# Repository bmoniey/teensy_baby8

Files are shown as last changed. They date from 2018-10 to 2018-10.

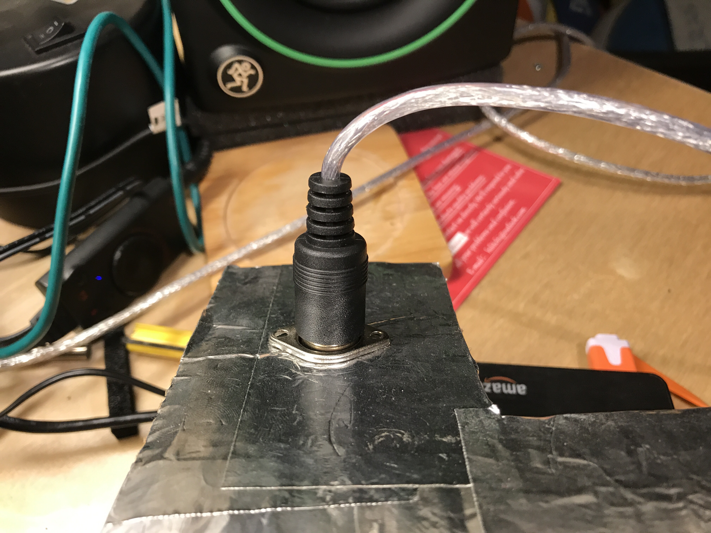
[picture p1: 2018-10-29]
doc/pics/IMG_2280.JPG

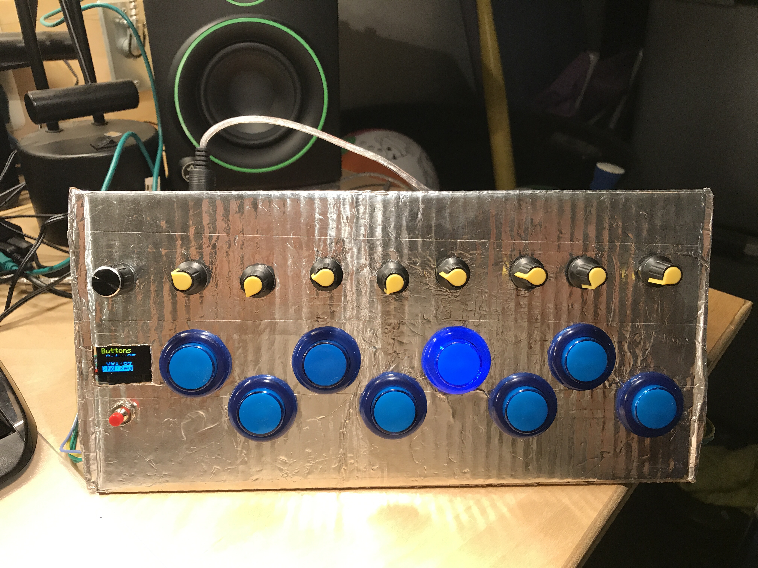
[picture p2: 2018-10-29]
doc/pics/IMG_2279.JPG

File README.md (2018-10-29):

# teensy_baby8
Music sequencer based on teensy3.2 micro

## 1. Features:

* 8 Steps, 32 divisions per step

* 8 Pots read on analog inputs. Each pot sets the values value of note for each step

* 8 Lighted buttons
	Lights to show which step is active
	Lights when button is pressed

## 2. Buttons:
	Regular Mode: Just to plays notes on a selected channel
	Skip Mode: Buttons cause sequencer to reset at the step of the pressed button

## 3. PCF8574
Uses PCF8574 IO expander to read buttons, drive LEDS and issue an interrupt when any of the input IO's change.
The design used 2 of the boards each driving 4 LEDS and reading 4 Buttons. The PCF8574 library is an adaptation of 
https://github.com/xreef/PCF8574_library

## 4. MIDI - This sequencer sends MIDI via serial port on Teensy 3.2
	Uses MIDI commands sent via serial to a program like Ableton Live.
	Needs a USB to MIDI adapter.

## 5. OLED Display SSD1306 128 x 64
* Used to provide menu interface to make changes to the behaviour of the sequencer
* Set BPM (beats per minute)
* Select MIDI channel
* Turn On/Off tracks
* Select Octave
* Set Note Velocity
* Select mode of operation for buttons

## 6. Encoder KY-40 (Amazon)
* Uses incremental encoder with push-button to navigate menu
* Custom class used to handle increment,decrement and push-button events.
provides tracker for position and direction, and interrupts.

## 7. Menu
Class which derives from the Adafruit SSD1306 and GFX Library for simple text based
menu system. Encoder moves focus up and down page. Depress button to select. While selected
the item can be manipulated. Changes take immediate effect!

If Adafruit libraries are not already installed in your arduino lib then see here:

https://github.com/adafruit/Adafruit_SSD1306
https://github.com/adafruit/Adafruit-GFX-Library

### 8 Menu Elements:

* Pages

* GotoItems: links to other pages

* ListItems: Items on a page that display as text strings

* IntItems: Items which control an integer number

* FloatItems: Items which control floating point numbers

## TODO:
1. Make Midi interface configurable so that the Teensy built in MIDI HID interface could be used. Would eliminate the need
for a MIDI interface. This project was tested using an inexpensive USB midi interface connected to a PC.
2. Add Gate and CV outs using the Teensy on-board DAC and digital IO.

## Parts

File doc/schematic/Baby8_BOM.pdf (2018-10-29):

Teensy Baby8 Sequencer BOM
Line | Part | Qnty | Supplier | Description | URL | Notes
1 | TEENSY32 | 1 | PJRC | Teensy USB Board, Version 3.2 | https://www.pjrc.com/store/teensy32.html
2 | KY-049 | 1 | Amazon | Gufastore 6pcs KY-040 Rotary Encoder Module with Knob Cap and Anti-static Tweezers for Arduino | https://www.amazon.com/gp/product/B07BN3DGBS/ref=oh_aui_detailpage_o00_s00?
3 | | | | Diymall 0.96" Inch Yellow Blue I2c IIC Serial Oled LCD LED Module 12864 128X64 for Arduino Display Raspberry PI 51 Msp420 Stim32 SCR | ie=UTF8&psc=1 https://www.amazon.com/gp/product/B00O2LLT30/ref=oh_aui_search_detailpage?ie=UTF8&psc=1
4 | USBMIDI | 1 | Amazon | SANOXY USB to MIDI Music Keyboard Interface 2 IN 1 Converter Cable | https://www.amazon.com/gp/product/B00VQTA0GS/ref=oh_aui_detailpage_o02_s00?
5 | PCF8574 | 2 | Amazon | WINGONEER 5Pcs PCF8574 IO Expansion Board I/O Expander I2C-Bus Evaluation Development Module | ie=UTF8&psc=1 https://www.amazon.com/gp/product/B07B949LNZ/ref=oh_aui_detailpage_o03_s00?ie=UTF8&psc=1
6 | MIDI_DIN | 1 | Amazon | CESS DIN Female 5-Pin Jack Socket Connector Panel Mount Soldering - 5 Pin MIDI DIN Socket (LW) (jcx) (4 Pack) | https://www.amazon.com/gp/product/B01GBT9RC0/ref=oh_aui_detailpage_o02_s01?ie=UTF8&psc=1
7 | HEADERS | 1 | Amazon | 20PCS 2.54mm Breakaway PCB Board 40Pin Male and Female Header Connector for Arduino Shield | https://www.amazon.com/gp/product/B01MQ48T2V/ref=oh_aui_detailpage_o05_s00?ie=UTF8&psc=1
8 | POTS | 2 | Amazon | Uxcell a15040700ux0380 5 Piece 10K Ohm 3 Terminals Linear Taper Rotary Audio B Type Potentiometer, B10K | https://www.amazon.com/gp/product/B019I13X5K/ref=oh_aui_detailpage_o05_s00?ie=UTF8&psc=1
9 | BUTTONS | 2 | Amazon | Reyann 6 Pcs/lot 5v LED Illuminated Arcade Push Button with Build-in Microswitch for Arcade Game Machines , Mame Game DIY & Arcade USB Cabinet DIY 28mm*33mm Blue | https://www.amazon.com/gp/product/B00XJ8UEQ0/ref=oh_aui_detailpage_o06_s01?ie=UTF8&psc=1
10 | PROTOBOARD | 1 | Amazon | AUSTOR 36 Pieces Double Sided PCB Board Prototype Kit, 5 Sizes Universal Printed Circuit Protoboard with Free Box, for DIY Soldering and Electronic Project | https://www.amazon.com/gp/product/B074X2GDH2/ref=oh_aui_detailpage_o05_s00?ie=UTF8&psc=1
11 | CRIMPCONN | 1 | Amazon | Dupont Connector Kit - 1004 pcs Crimp Connector Kit with Dupont Wire Connectors and Ribbon Cable - A Set of Male and Female 2.54 mm Dupont Connectors and Crimp Pins from Plusivo | https://www.amazon.com/gp/product/B078RRPRQZ/ref=oh_aui_detailpage_o05_s00?ie=UTF8&psc=1
12 | USBHUB | 1 | Amazon | AmazonBasics 4 Port USB 3.0 Hub with 5V/2.5A power adapter | https://www.amazon.com/gp/product/B00DQFGH80/ref=oh_aui_detailpage_o03_s02?ie=UTF8&psc=1
13 | WIRE | 1 | Amazon | Striveday™ 26 AWG Flexible Silicone Wire Electric wire 26 gauge Coper Hook Up Wire 300V Cables electronic stranded wire cable electrics DIY BOX-1 | https://www.amazon.com/gp/product/B01KQ2NURG/ref=oh_aui_detailpage_o06_s03?ie=UTF8&psc=1
14 | USBCABLE | 1 | Amazon | Short USB Cable, OKRAY 10 Pack Colorful Micro USB 2.0 Charging Data Sync Cable Cord Compatible for Samsung, Android Phone, Tablet, Nexus, HTC, Nokia, LG, Sony, Many Digital Cameras-0.66ft (7.87 Inch) | https://www.amazon.com/gp/product/B00R5GZJR6/ref=oh_aui_detailpage_o01_s01?ie=UTF8&psc=1
15 | RESNET | 1 | Amazon | Electronics-Salon Thick Film Network Resistor Assortment Kit, Array Resistor, Bussed Type, 1/8W, SIP-5 and SIP-9 470 1K 4.7K 10K 47K | https://www.amazon.com/gp/product/B016MKHX7E/ref=oh_aui_detailpage_o03_s00?ie=UTF8&psc=1
16 | CAPS | 1 | Amazon | Ceramic Capacitor Assortment Kit - Set of 600 Small Assorted Capacitors from 100 nF to 10 uF in a Box - Non-Polarized Disc Capacitor Component Set from Plusivo | https://www.amazon.com/gp/product/B078PHKNNT/ref=oh_aui_detailpage_o03_s01?ie=UTF8&psc=1
17 | RESISTORS | 1 | Amazon | EAONE 850 Pieces 30 Values 1% Resistor Kit, 0 Ohm-1M Ohm 1/4W Metal Film Resistors Assortment for DIY and Experiments | https://www.amazon.com/gp/product/B076LH75JQ/ref=oh_aui_detailpage_o03_s02?ie=UTF8&psc=1

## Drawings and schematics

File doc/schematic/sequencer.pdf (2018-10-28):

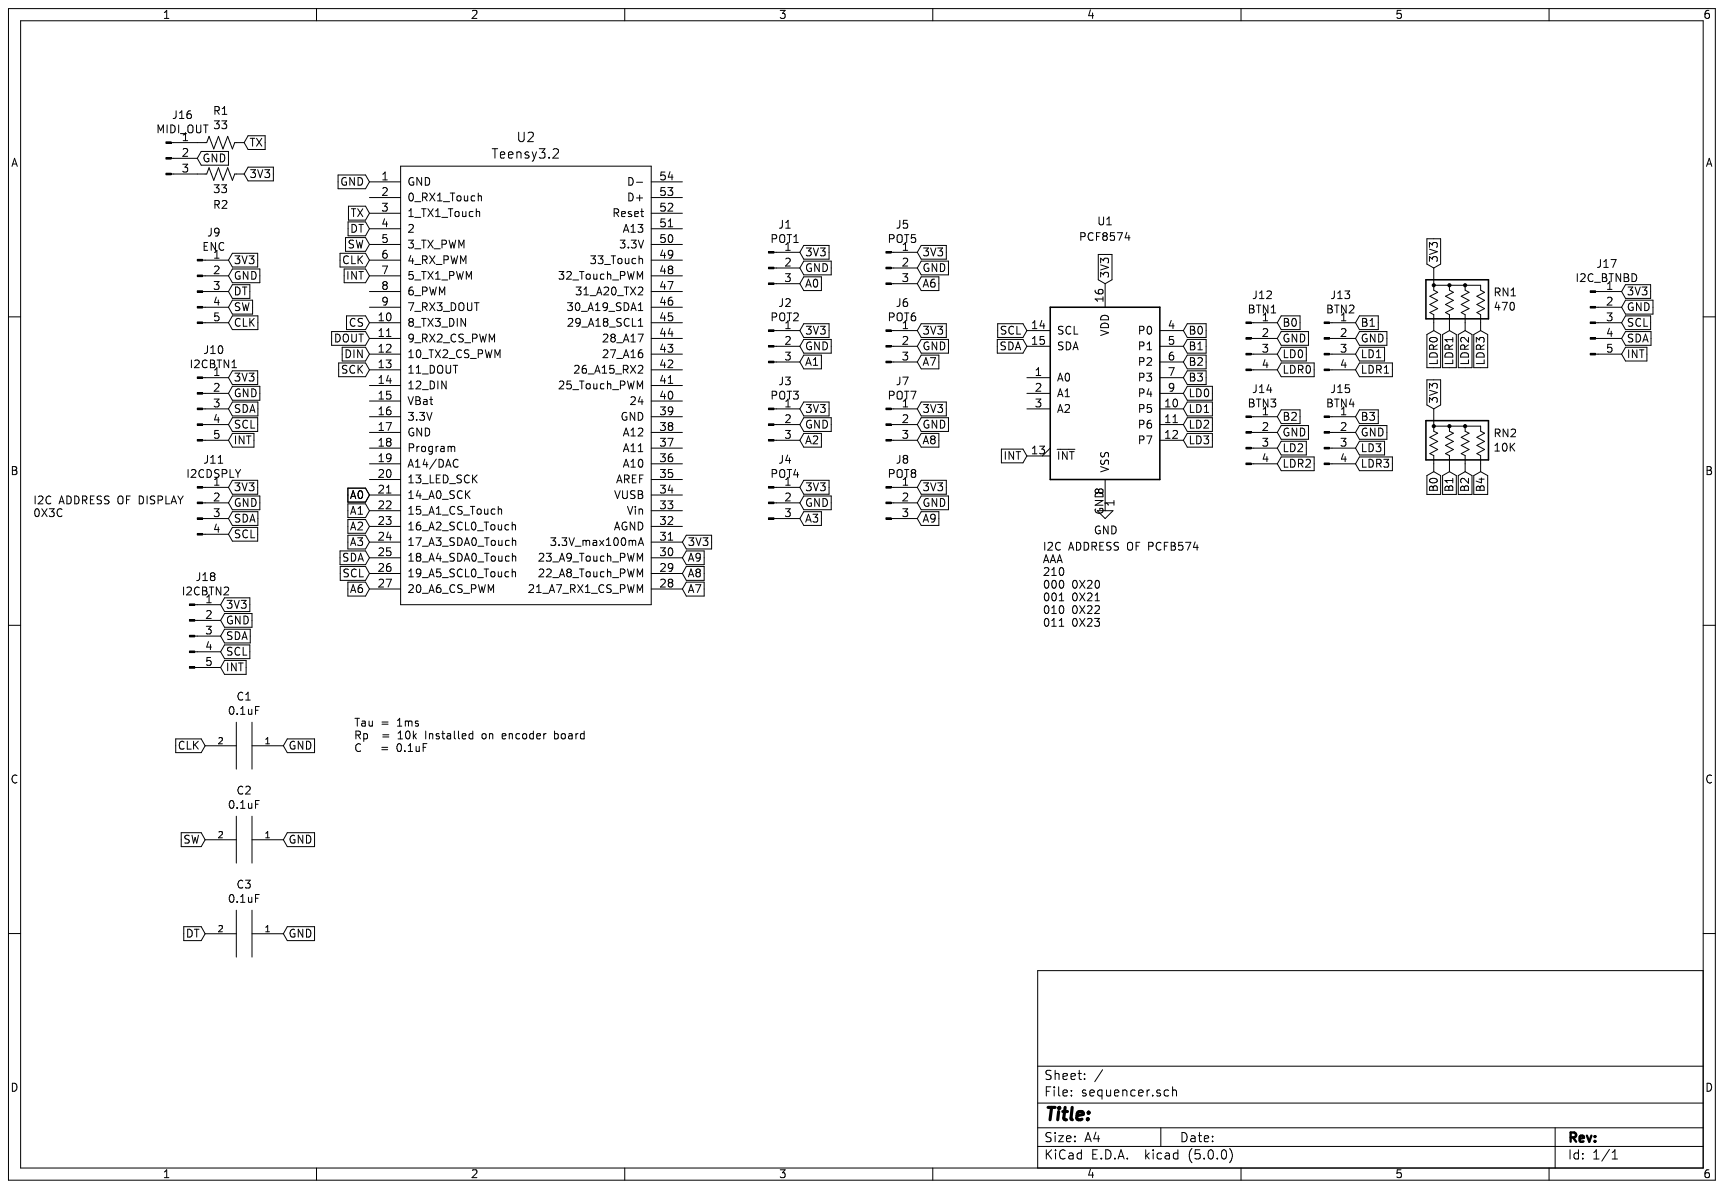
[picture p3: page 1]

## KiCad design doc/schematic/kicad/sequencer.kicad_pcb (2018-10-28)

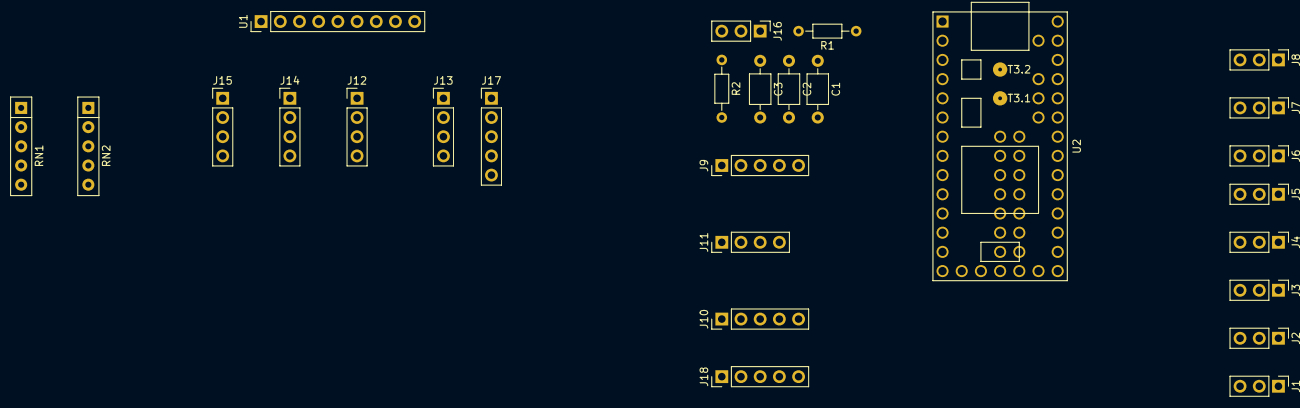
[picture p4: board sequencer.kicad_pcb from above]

Board: 2 copper layers, 27 parts (0 on the bottom side), 28 nets, no tracks yet.

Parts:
C1, C2, C3: 0.1uF; C_Axial_L3.8mm_D2.6mm_P7.50mm_Horizontal
J1: POT1; PinHeader_1x03_P2.54mm_Vertical
J2: POT2; PinHeader_1x03_P2.54mm_Vertical
J3: POT3; PinHeader_1x03_P2.54mm_Vertical
J4: POT4; PinHeader_1x03_P2.54mm_Vertical
J5: POT5; PinHeader_1x03_P2.54mm_Vertical
J6: POT6; PinHeader_1x03_P2.54mm_Vertical
J7: POT7; PinHeader_1x03_P2.54mm_Vertical
J8: POT8; PinHeader_1x03_P2.54mm_Vertical
J9: ENC; PinHeader_1x05_P2.54mm_Vertical
J10: I2CBTN1; PinHeader_1x05_P2.54mm_Vertical
J11: I2CDSPLY; PinHeader_1x04_P2.54mm_Vertical
J12: BTN1; PinHeader_1x04_P2.54mm_Vertical
J13: BTN2; PinHeader_1x04_P2.54mm_Vertical
J14: BTN3; PinHeader_1x04_P2.54mm_Vertical
J15: BTN4; PinHeader_1x04_P2.54mm_Vertical
J16: MIDI_OUT; PinHeader_1x03_P2.54mm_Vertical
J17: I2C_BTNBD; PinHeader_1x05_P2.54mm_Vertical
J18: I2CBTN2; PinHeader_1x05_P2.54mm_Vertical
R1, R2: 33; R_Axial_DIN0204_L3.6mm_D1.6mm_P7.62mm_Horizontal
RN1: 470; R_Array_SIP5
RN2: 10K; R_Array_SIP5
U1: PCF8574; PinHeader_1x09_P2.54mm_Vertical
U2: Teensy3.2; Teensy30_31_32_LC

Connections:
3V3: J1.1, J2.1, J3.1, J4.1, J5.1, J6.1, J7.1, J8.1, J9.1, J10.1, J11.1, J17.1, J18.1, R2.2, RN1.1, RN2.1, U2.31
A0: J1.3, U2.21
A1: J2.3, U2.22
A2: J3.3, U2.23
A3: J4.3, U2.24
A6: J5.3, U2.27
A7: J6.3, U2.28
A8: J7.3, U2.29
A9: J8.3, U2.30
B0: J12.1, RN2.2, U1.4
B1: J13.1, RN2.3, U1.5
B2: J14.1, RN2.4, U1.6
B3: J15.1, U1.7
CLK: C1.2, J9.5, U2.6
DT: C3.2, J9.3, U2.4
GND: C1.1, C2.1, C3.1, J1.2, J2.2, J3.2, J4.2, J5.2, J6.2, J7.2, J8.2, J9.2, J10.2, J11.2, J12.2, J13.2, J14.2, J15.2, J16.2, J17.2, J18.2, U1.8, U2.1
INT: J10.5, J17.5, J18.5, U2.7
LD0: J12.3, U1.9
LDR0: J12.4, RN1.2
LDR1: J13.4, RN1.3
LDR2: J14.4, RN1.4
LDR3: J15.4, RN1.5
unnamed: J16.1, R1.2
unnamed: J16.3, R2.1
SCL: J10.4, J11.4, J17.3, J18.4, U2.26
SDA: J10.3, J11.3, J17.4, J18.3, U2.25
SW: C2.2, J9.4, U2.5
TX: R1.1, U2.3

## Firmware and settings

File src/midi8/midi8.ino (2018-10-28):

#include "Arduino.h"
#include "StepSequencer.h"

StepSequencer sqncr(120);

/*
 * Forward declarations for the interrupt service routines
 */
void readButtonsISR(void);
void encoderSwISR(void);
void encoderClkISR(void);

char cstr[255];

void setup() {
 Serial.begin(9600);  
 
 digitalWrite(13,ON);
 
 //button boards interrupts are on pin5
 pinMode(5, INPUT_PULLUP);
 attachInterrupt(digitalPinToInterrupt(5), readButtonsISR, FALLING );
 pinMode(ENC_DT_PIN, INPUT_PULLUP);
 pinMode(ENC_CLK_PIN, INPUT_PULLUP);
 pinMode(ENC_SW_PIN, INPUT_PULLUP);
  
 attachInterrupt(digitalPinToInterrupt(ENC_CLK_PIN), encoderClkISR, FALLING );//attach interrupts if using interrupts
 attachInterrupt(digitalPinToInterrupt(ENC_SW_PIN), encoderSwISR, CHANGE );//attach interrupts if using interrupts
 
 sqncr.begin();
 
 delay(1000);
 Serial.println("Starting Midi7");
}

void loop() { 
  sqncr.loop();
}

void readButtonsISR(void){
  sqncr.readButtonISR();
}

void encoderClkISR(void){
  sqncr.readEncClkISR();
  //Serial.print(".");
}

void encoderSwISR(void){
  sqncr.readEncSwISR();
  //Serial.print("-");
}

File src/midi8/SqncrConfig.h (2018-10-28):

/**
* #defines used by the sequencer and it subclasses
*/
#ifndef SQNCR_CONFIG_H
#define SQNCR_CONFIG_H

#define NSTEP 8  //Number of steps the sequencer supports
				 //each step is a beat
#define RSTEP 32 //Number of counts per step
				 //defines number of beat fractions
#define  PCF8574_ISR_PIN 5
#define  PCF8574_ADDR_ARRY {0x20,0x21} //should be as long as there are boards
                       //should also be in order from lowest to highest
#define  PCF8574_NUM_BOARDS 2
  
#define NTRACK 1 //number of tracks i.e. could have multiple tracks
#define TICK_US(x)	(60000000/RSTEP/(x));
#define TMR_MAX      0xFFFFFFFF //microseconds
#define CLK_TIME_TO_NORM 0x7FFFFFFF //microseconds
#define MIDI_SERIAL Serial1
#define MIDI_SERIAL_SPEED 31250
#define BPM_MAX  999
#define BPM_MIN   10

#define DSPLY_I2C_ADDR 0x3C


#define LED_PIN_ONBOARD 13

#define BTN_LONGPRESS_MS 500

#define MIDI_NOTE_ON 0x90
#define MIDI_NOTE_OFF 0x80
#define ON 1
#define OFF 0

// Uncomment to enable printing out nice debug messages.
#define STEP_SEQUENCER_DEBUG

// Define where debug output will be printed.
#define SQNCR_DEBUG_PRINTER Serial

// Setup debug printing macros.
#ifdef STEP_SEQUENCER_DEBUG
	  #define SQNCR_DEBUG_PRINT(...) { DEBUG_PRINTER.print(__VA_ARGS__); }
	  #define SQNCR_DEBUG_PRINTLN(...) { DEBUG_PRINTER.println(__VA_ARGS__); }
#else
	  #define SQNCR_DEBUG_PRINT(...) {}
	  #define SQNCR_DEBUG_PRINTLN(...) {}
#endif

#endif

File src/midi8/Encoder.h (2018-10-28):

/**
* This is for a KY-040 encoder I picke up on Amazon
* Pins
* 1. 3V3
* 2. GND
* 3. DT   added 100nF cap
* 4. SW   added 100nF cap
* 5. CLK  added 100nF cap
*
*/
#ifndef ENCODER_H
#define ENCODER_H
#include "Arduino.h"
#define  ENC_DT_PIN  2
#define  ENC_CLK_PIN 4
#define  ENC_SW_PIN  3
#define  ENC_DT_BIT   0x01
#define  ENC_CLK_BIT  0x02
#define  ENC_SW_BIT   0x04
#define  ENC_BTN_LONG_PRESS_MS 500
#define  ENC_DIR_CW_POS (0)
#define  ENC_DIR_CW_NEG (1)
#define  ENC_PMAX    ((int16_t)32767)
#define  ENC_PMIN    ((int16_t)-32767)

class Encoder{
	public:
  Encoder(){};
  Encoder(uint8_t dir_);
  Encoder(uint8_t dir_, int16_t pmax_, int16_t pmin_);
  Encoder(uint8_t dir_, int16_t pmax_, int16_t pmin_,int16_t pos_);
	void setup(void);
	void read(void);//call this to poll the both the switch and encoder
	void  isrReadSwPin(void);//call this from the switch pin interrupt
  void  isrReadClkPin(void);//call this from the Clock pin interrupt 
	int16_t  getPos(void);//returns current position
	int16_t  getDir(void);//returns direction 1=ccw,0=stop,-1=ccw
  uint8_t  getBtn(void);
  uint8_t  getBtnDn(void);
  uint8_t  getBtnUp(void);
  uint8_t  getBtnDnLong(void);
  void  clrBtnDn(void);
  void  clrBtnUp(void);
  void  clrBtnDnLong(void);
  void  clrBtnAll(void);  
  void     readSW(void);
  void  encoderSetDir(uint8_t dir);
  uint8_t encDatAvail(void);//Use this to check if there is new encoder position available
                            //calling this resets the status so will fail on second call if no new data is available
  void resetPos(int16_t value);
  void setPminPmax(int16_t pmax_,int16_t pmin_);
  
	private:
  uint8_t newDat;
  uint8_t encDir; //holds setting for direction output
  void readDT();
	uint8_t  sw[2];
  uint8_t  clk[2];
	uint8_t  enc[2];//holds last reads of the DT and CLK pin and sw pin
	int16_t  pos[2];//holds the last 2 position values
  int16_t  pmin = ENC_PMIN;
  int16_t  pmax = ENC_PMAX;
	int16_t  dir;//
	uint8_t  btn;//current button state
	uint8_t  btnDn;//button down event
	uint8_t  btnUp;//button up event
	uint8_t  btnDnLong;//button Long Press
	uint32_t btnDnTmr;//holds the millis() when the button was pressed down
	
}; 
#endif

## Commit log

2018-10-28 Intial Commit of docs and src
    [sequencer.kicad_pcb, sequencer.sch]
2018-10-29 added some pics of the cardboard prototype
2018-10-29 Added pdf print of BOM
